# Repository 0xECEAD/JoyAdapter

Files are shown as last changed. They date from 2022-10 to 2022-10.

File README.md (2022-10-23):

# JoyAdapter

Another 8-bit Atari Joystick to USB adapter.

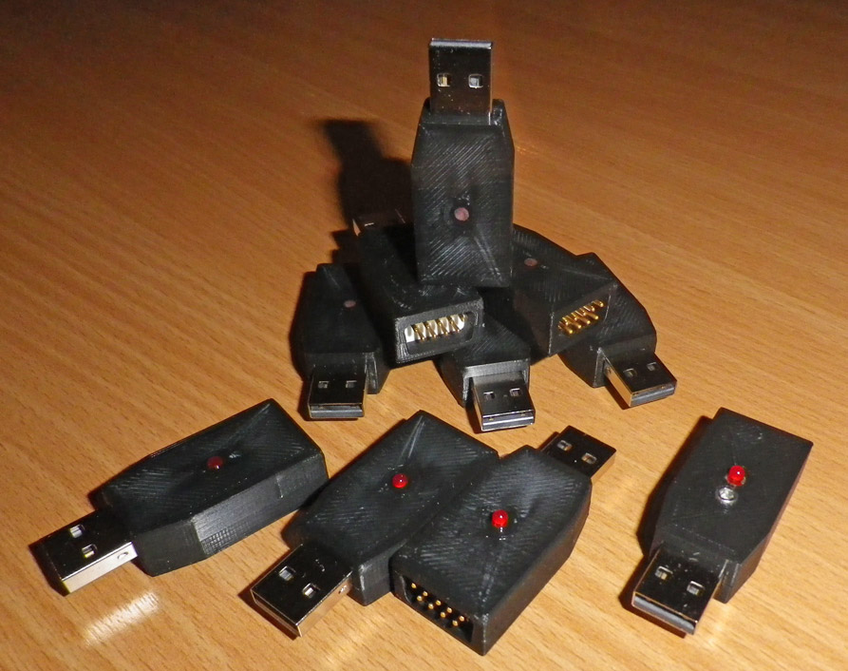
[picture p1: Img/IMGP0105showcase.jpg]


There are dozens of similar converters available, but I wanted one in a sleek form factor.
It is about the size of the iconic Atari connector itself. 

It is a standard USB-HID class (Joystick) device, generally no drivers required. It has 2 buttons and 2-axis (non configurable). No POT/Paddle inputs only digital (switch to ground) inputs. 

The LED flashes on connect and movement/button action.

## PCB:

schematic: [pdf](Board/schema.pdf)
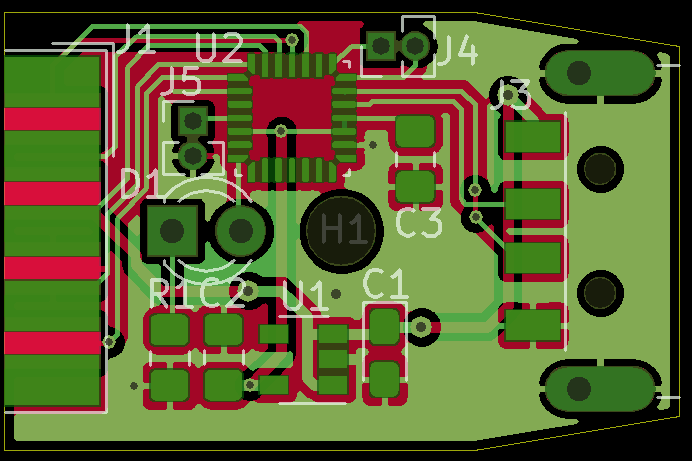
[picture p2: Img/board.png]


### Pinout J1 Atari:
Connector  [Wikipedia](https://en.wikipedia.org/wiki/Atari_joystick_port)

| Pin | Function | Pin | Function |
| --- | --- | --- | --- |
| 1 | Up | 6 | Button 1 |
| 2 | Down | 7 | +5V |
| 3 | Left | 8 | Ground |
| 4 | Right | 9 | Button 2 |
| 5 | N.C. |

**Note:** +5V on pin 7 (not fused or limitied or protected) can damage you USB host if shorted.
5V is not required for most (passive) joysticks i know, so you could pull pin 7 the out of the connector to be safe.

### Parts: 

|Qty|Ref(s)|Value|Manufacturer|Note|Datasheet|
| --- | --- | --- | --- | --- | --- |
|1|C1|4u7F||Tantalum||
|1|C2|1uF||||
|1|C3|100nF||||
|1|D1|L-424IDT|Kingbright|FlatTop|[pdf](https://nl.mouser.com/datasheet/2/216/L-424IDT(Ver.12A)-795377.pdf)|
|1|H1|MountingHole||2.5mm||
|1|J1|DB9 Male||Solder Straight, shell removed||
|1|J3|USB PLUG Type A|Keystone Electronics|SMD|[pdf](https://www.mouser.com/datasheet/2/215/31-744008.pdf)|
|2|J4, J5|Connector 1x2||pitch 1.27mm||
|1|R1|68Ω||||
|1|U1|XC6220B331MR|Torex Semiconductor||[pdf](https://www.torexsemi.com/file/xc6220/XC6220.pdf)|
|1|U2|STM32F042G6Ux|STMicroelectronics|QFN28 4x4mm|[pdf](http://www.st.com/st-web-ui/static/active/en/resource/technical/document/datasheet/DM00105814.pdf)|

Notes: 
- The J1 shell is actually a **DE**-type (common mistake, even KiCad fails this)
- Any low-drop voltage regulator for U1 (SOT23-5 package) either 3V or 3V3, e.q. XC6220B331MR or AP7383-30W5.
- U2 is a STM32F042G6Ux controller, it features crystal-less USB, and 5V tolerant inputs.
- The SWD programming connector was split into two, J4 and J5 due to size restrictions.

### Construction:

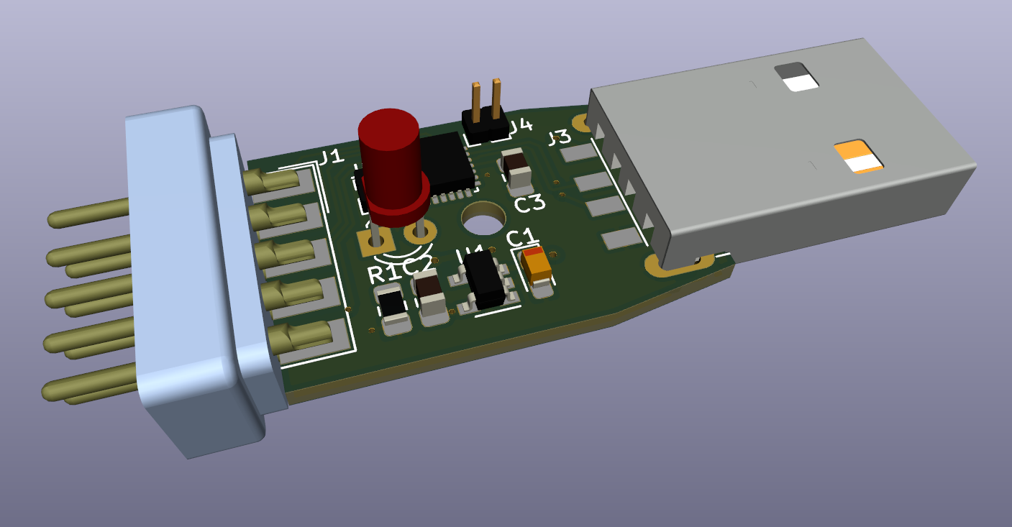
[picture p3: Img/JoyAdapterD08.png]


Manufacture the PCB with FR4 thickness 1.2mm. (Normal 1.6mm will not fit between the pins of J1).

J1 is a standard DSUB 9pin Male connector. Remove the shell with cutters and pliers and some force.
The remaining inner part can be mounted with the PCB between the pins. 

Solder the LED so the flat top aligns nicely with the top side of the case.

## Case:

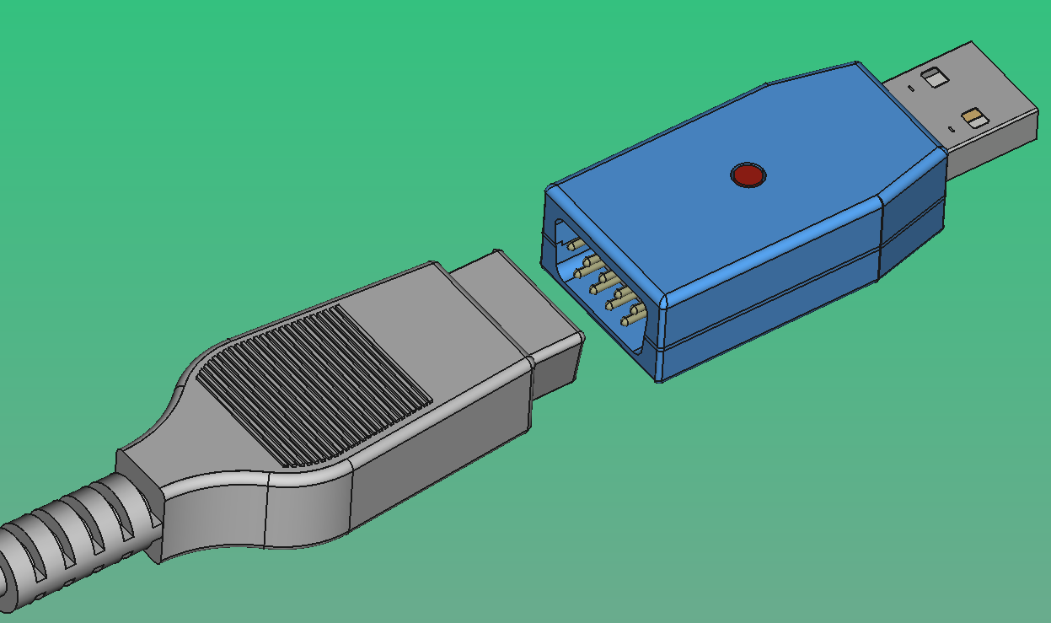
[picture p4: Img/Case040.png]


Print the Bottom and Top part of the case on your 3D printer (i used a Ultimaker S5).
Use a M2.5 x 8mm Hex Socket Head Cap Screw to join bottom case and top case together.

## Software:

Project setup was done with [STM CubeMX](https://www.st.com/en/development-tools/stm32cubemx.html), further implementation with [VisualGDB](https://visualgdb.com/).
The [Descriptor Tool](https://www.usb.org/document-library/hid-descriptor-tool) was used to design the HID Report.
Its a fairly simple source code, you can adjust it to you favorite development environment.

### Latency:

Updates 100x per second, reason mostly to reduce contact bounce. 
In theory you could send at 1kHz for LowSpeed USB or 8kHz for FullSpeed USB, but you may want to include some debounce logic.
Current implementation thus updates every change in a 10ms interval, faster then most screen refresh rates of retro games. 

## Compatibility
Windows 98/XP/Vista/7/8/10/11, Mac OSX, Linux, RaspberryPI, MiSTer. 

### Tested Devices
The Arcade by S.T.C. Rotterdam

### Design Software

KiCad v6.0.7 + GerberView v2.6.1
FreeCAD v0.19
Ultimaker Cura v4.6.2

Descriptor Tool, Version 2.4
VisualGDB v5.6r8 + STM CubeMX v6.5

### Demo
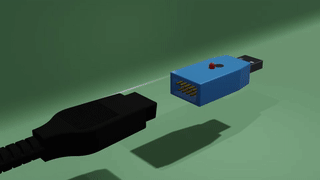
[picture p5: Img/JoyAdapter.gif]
movie


## Credits
(c) 2019 Enceladus

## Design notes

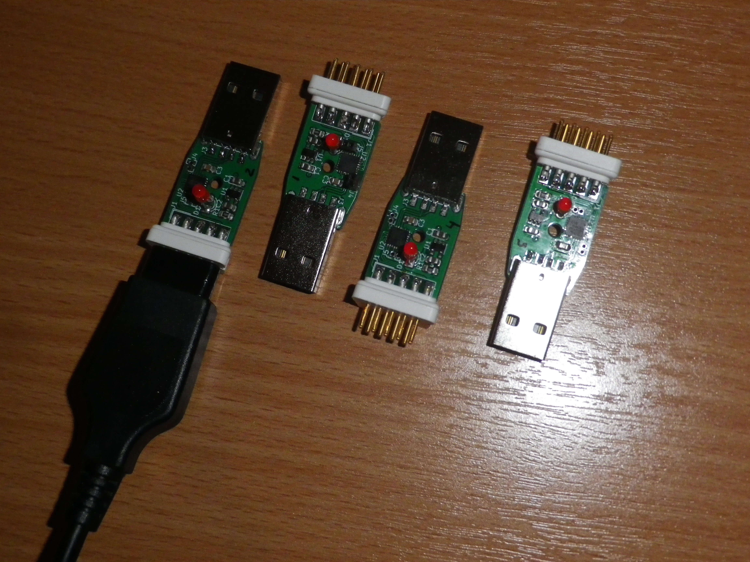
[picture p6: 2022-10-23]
Img/IMGP0094.JPG

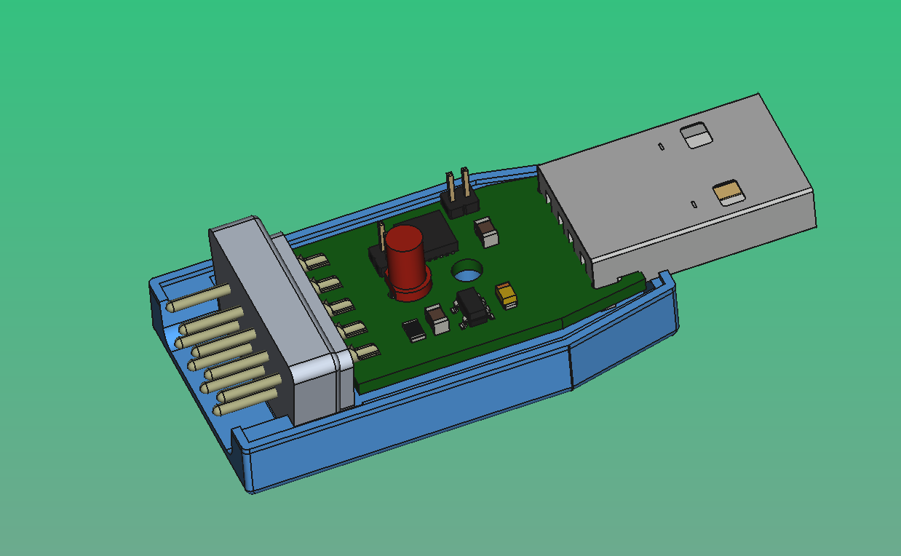
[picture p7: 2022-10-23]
Img/Case041.png

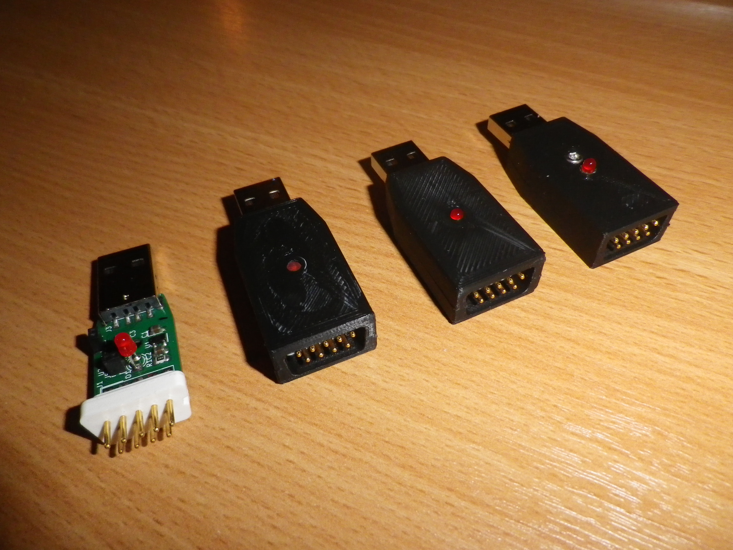
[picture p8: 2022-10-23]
Img/IMGP0100.JPG

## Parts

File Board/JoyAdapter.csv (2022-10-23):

Source: | D:\tmp\JoyAdapter.kicad_sch
Date: | 19/10/2022 13:25:23
Tool: | Eeschema (6.0.7)
Generator: | D:\Tools\KiCad\bin\scripting\plugins/bom_csv_grouped_by_value.py
Component Count: | 12
Individual Components:
Item | Qty | Reference(s) | Value | LibPart | Footprint | Datasheet
 |  | C1 | 4u7F | Device:C_Polarized |  | ~
 |  | C2 | 1uF | Device:C | Capacitor_SMD:C_0805_2012Metric_Pad1.15x1.40mm_HandSolder | ~
 |  | C3 | 100nF | Device:C | Capacitor_SMD:C_0805_2012Metric_Pad1.15x1.40mm_HandSolder | ~
 |  | D1 | L-424IDT | Device:LED | LED_THT:LED_D3.0mm_FlatTop | ~
 |  | H1 | MountingHole | Mechanical:MountingHole | MountingHole:MountingHole_2.5mm | ~
 |  | J1 | DB9_Male | Connector:DB9_Male | Parts:DSUB-9_Male_EdgeMount_P2.77mm | ~
 |  | J3 | USB_B | Connector:USB_B | Parts:USB_A_Lumberg_2410-08 | ~
 |  | J4 | Conn_01x02 | Connector_Generic:Conn_01x02 | Connector_PinHeader_1.27mm:PinHeader_1x02_P1.27mm_Vertical | ~
 |  | J5 | Conn_01x02 | Connector_Generic:Conn_01x02 | Connector_PinHeader_1.27mm:PinHeader_1x02_P1.27mm_Vertical | ~
 |  | R1 | 68 | Device:R | Resistor_SMD:R_0805_2012Metric_Pad1.15x1.40mm_HandSolder | ~
 |  | U1 | XC6220B331MR | Regulator_Linear:XC6220B331MR | Package_TO_SOT_SMD:SOT-23-5 | https://www.torexsemi.com/file/xc6220/XC6220.pdf
 |  | U2 | STM32F042G6Ux | MCU_ST_STM32F0:STM32F042G6Ux | Package_DFN_QFN:QFN-28_4x4mm_P0.5mm | http://www.st.com/st-web-ui/static/active/en/resource/technical/document/datasheet/DM00105814.pdf
Collated Components:
Item | Qty | Reference(s) | Value | LibPart | Footprint | Datasheet
1 | 1 | C1 | 4u7F | Device:C_Polarized |  | ~
2 | 1 | C2 | 1uF | Device:C | Capacitor_SMD:C_0805_2012Metric_Pad1.15x1.40mm_HandSolder | ~
3 | 1 | C3 | 100nF | Device:C | Capacitor_SMD:C_0805_2012Metric_Pad1.15x1.40mm_HandSolder | ~
4 | 1 | D1 | L-424IDT | Device:LED | LED_THT:LED_D3.0mm_FlatTop | ~
5 | 1 | H1 | MountingHole | Mechanical:MountingHole | MountingHole:MountingHole_2.5mm | ~
6 | 1 | J1 | DB9_Male | Connector:DB9_Male | Parts:DSUB-9_Male_EdgeMount_P2.77mm | ~
7 | 1 | J3 | USB_B | Connector:USB_B | Parts:USB_A_Lumberg_2410-08 | ~
8 | 2 | J4, J5 | Conn_01x02 | Connector_Generic:Conn_01x02 | Connector_PinHeader_1.27mm:PinHeader_1x02_P1.27mm_Vertical | ~
9 | 1 | R1 | 68 | Device:R | Resistor_SMD:R_0805_2012Metric_Pad1.15x1.40mm_HandSolder | ~
10 | 1 | U1 | XC6220B331MR | Regulator_Linear:XC6220B331MR | Package_TO_SOT_SMD:SOT-23-5 | https://www.torexsemi.com/file/xc6220/XC6220.pdf
11 | 1 | U2 | STM32F042G6Ux | MCU_ST_STM32F0:STM32F042G6Ux | Package_DFN_QFN:QFN-28_4x4mm_P0.5mm | http://www.st.com/st-web-ui/static/active/en/resource/technical/document/datasheet/DM00105814.pdf

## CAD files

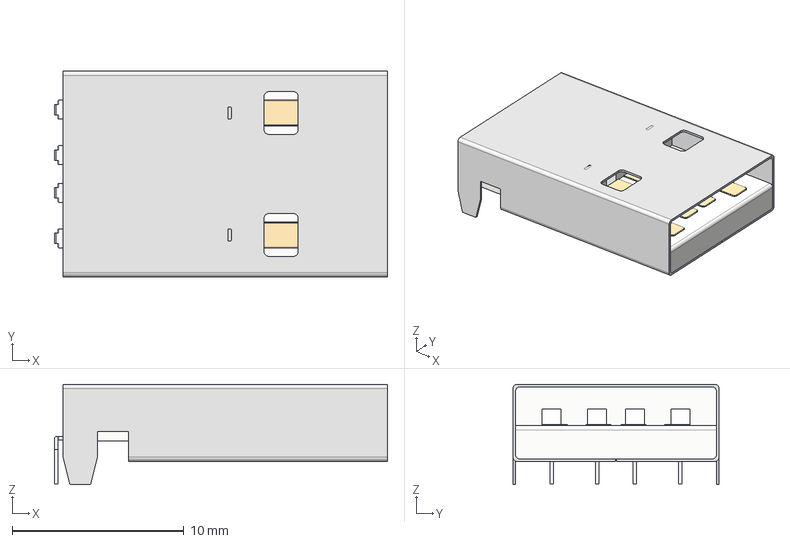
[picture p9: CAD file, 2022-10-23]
Board/USB A PCB Connector.step
19.4 x 12.0 x 5.85 mm

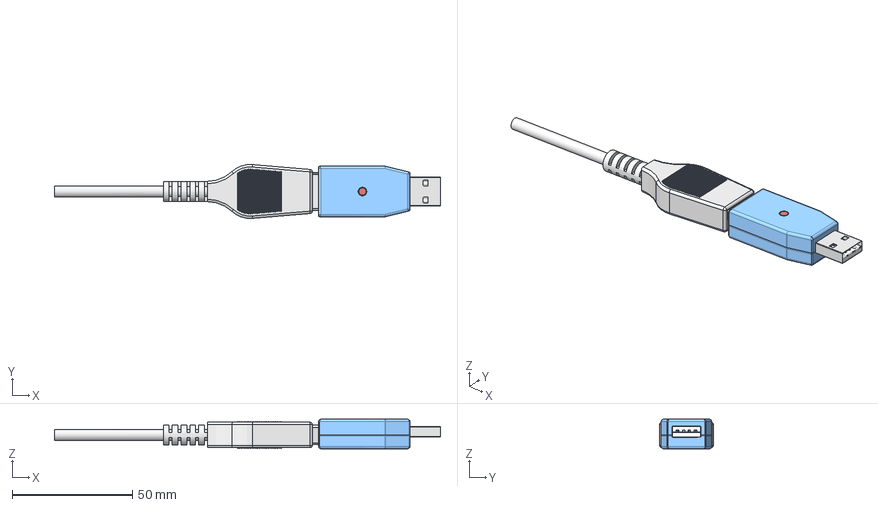
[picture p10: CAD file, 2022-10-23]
Case/JoyAdapter.FCStd
160.3 x 22.4 x 12.3 mm
M2.5x8
FinalTop
FinalBottom

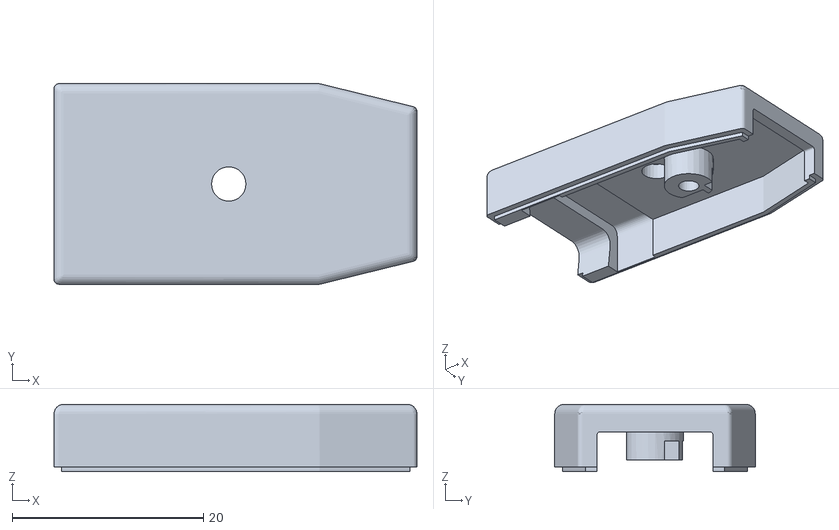
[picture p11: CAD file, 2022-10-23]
Release/Stl/CaseTop.stl
38.0 x 21.0 x 7.05

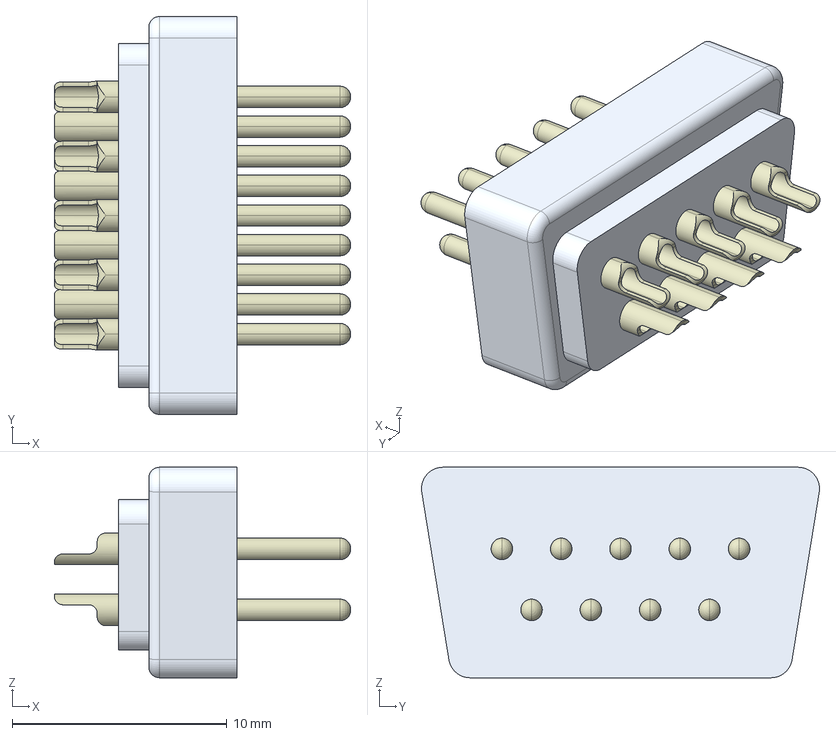
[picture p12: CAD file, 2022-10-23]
Board/DE9-P.step
13.8 x 18.5 x 9.80 mm
Solder3
Pin3
Solder1
Solder2
Solder4
Solder5
Pin1
Pin2
Pin4
Pin5
Solder7
Pin7
Solder8
Pin8
Solder6
Pin6
Solder9
Pin9

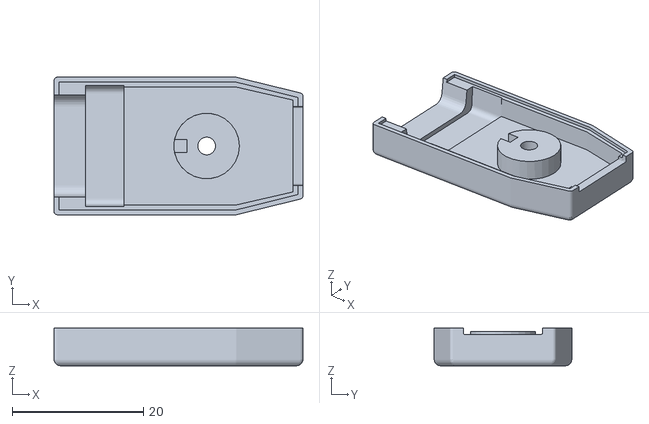
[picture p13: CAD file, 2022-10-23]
Release/Stl/CaseBottom.stl
38.0 x 21.0 x 5.75

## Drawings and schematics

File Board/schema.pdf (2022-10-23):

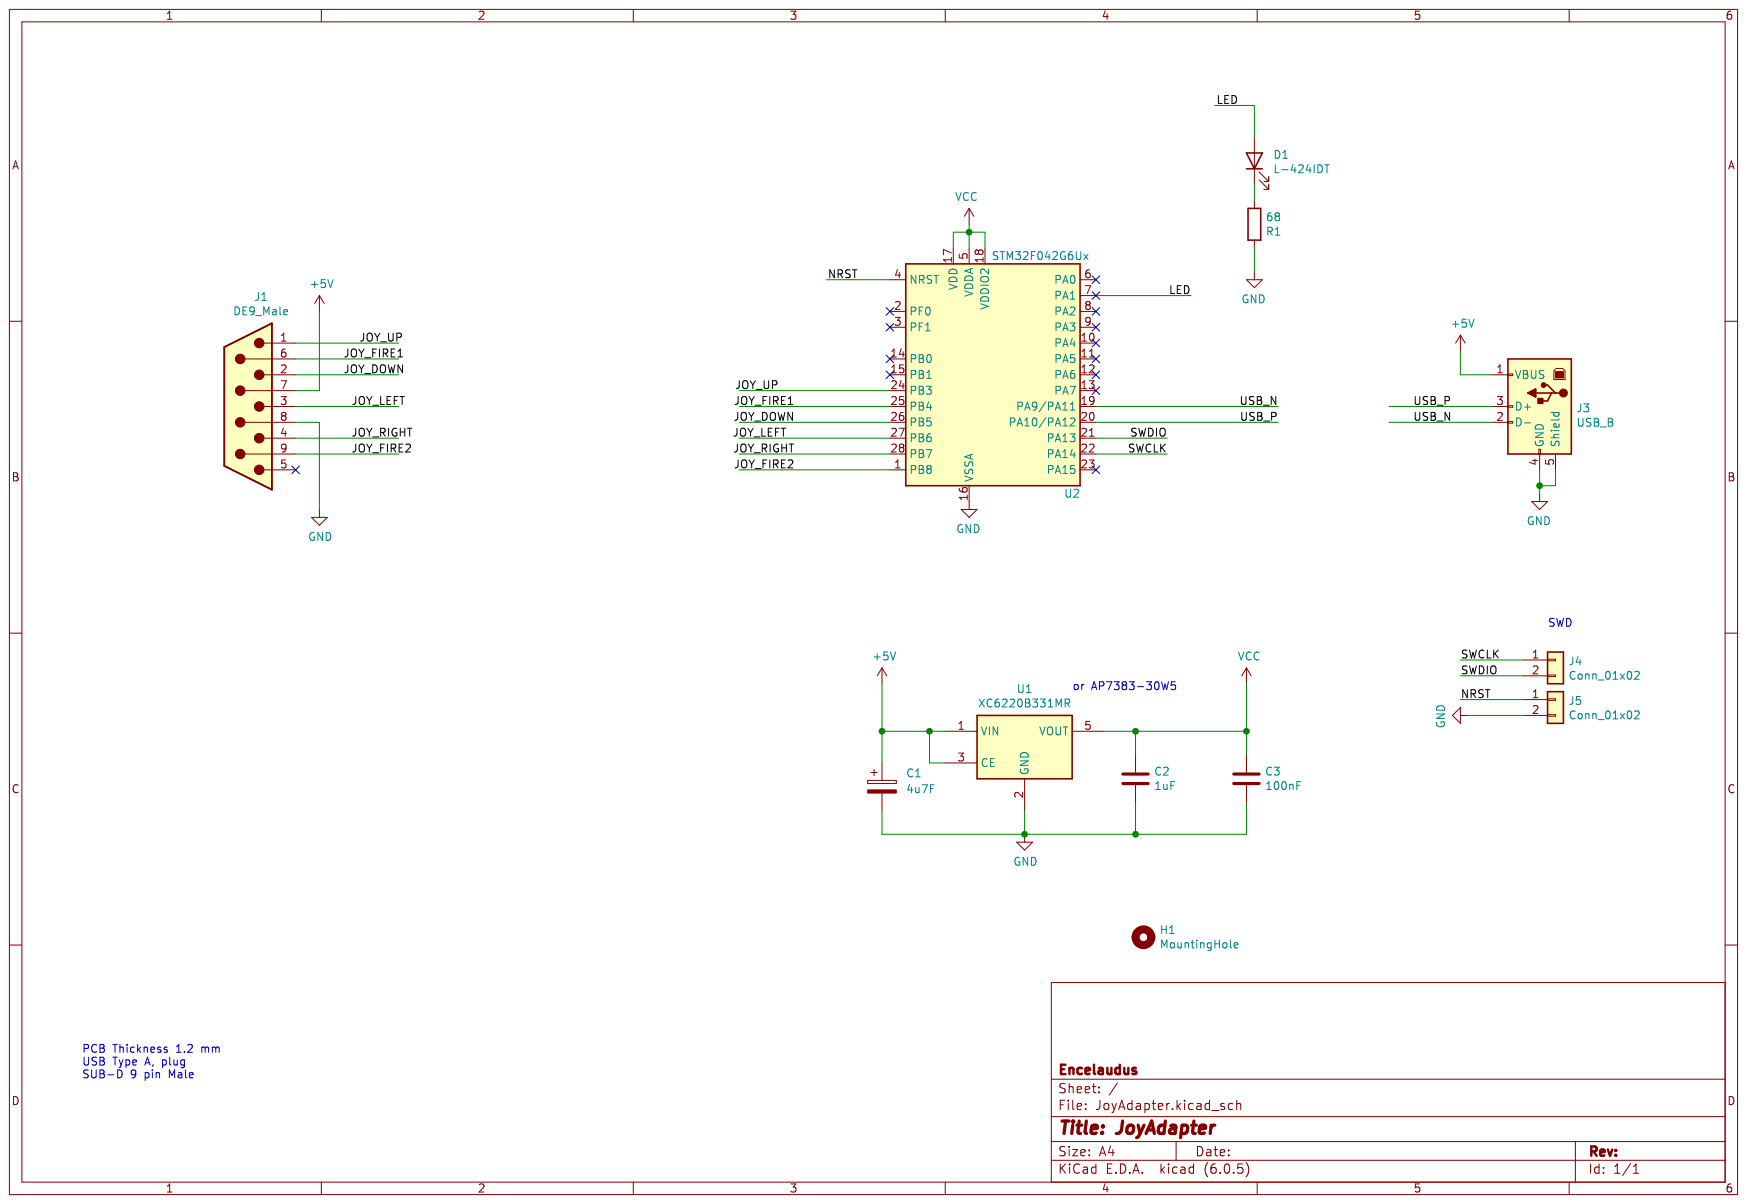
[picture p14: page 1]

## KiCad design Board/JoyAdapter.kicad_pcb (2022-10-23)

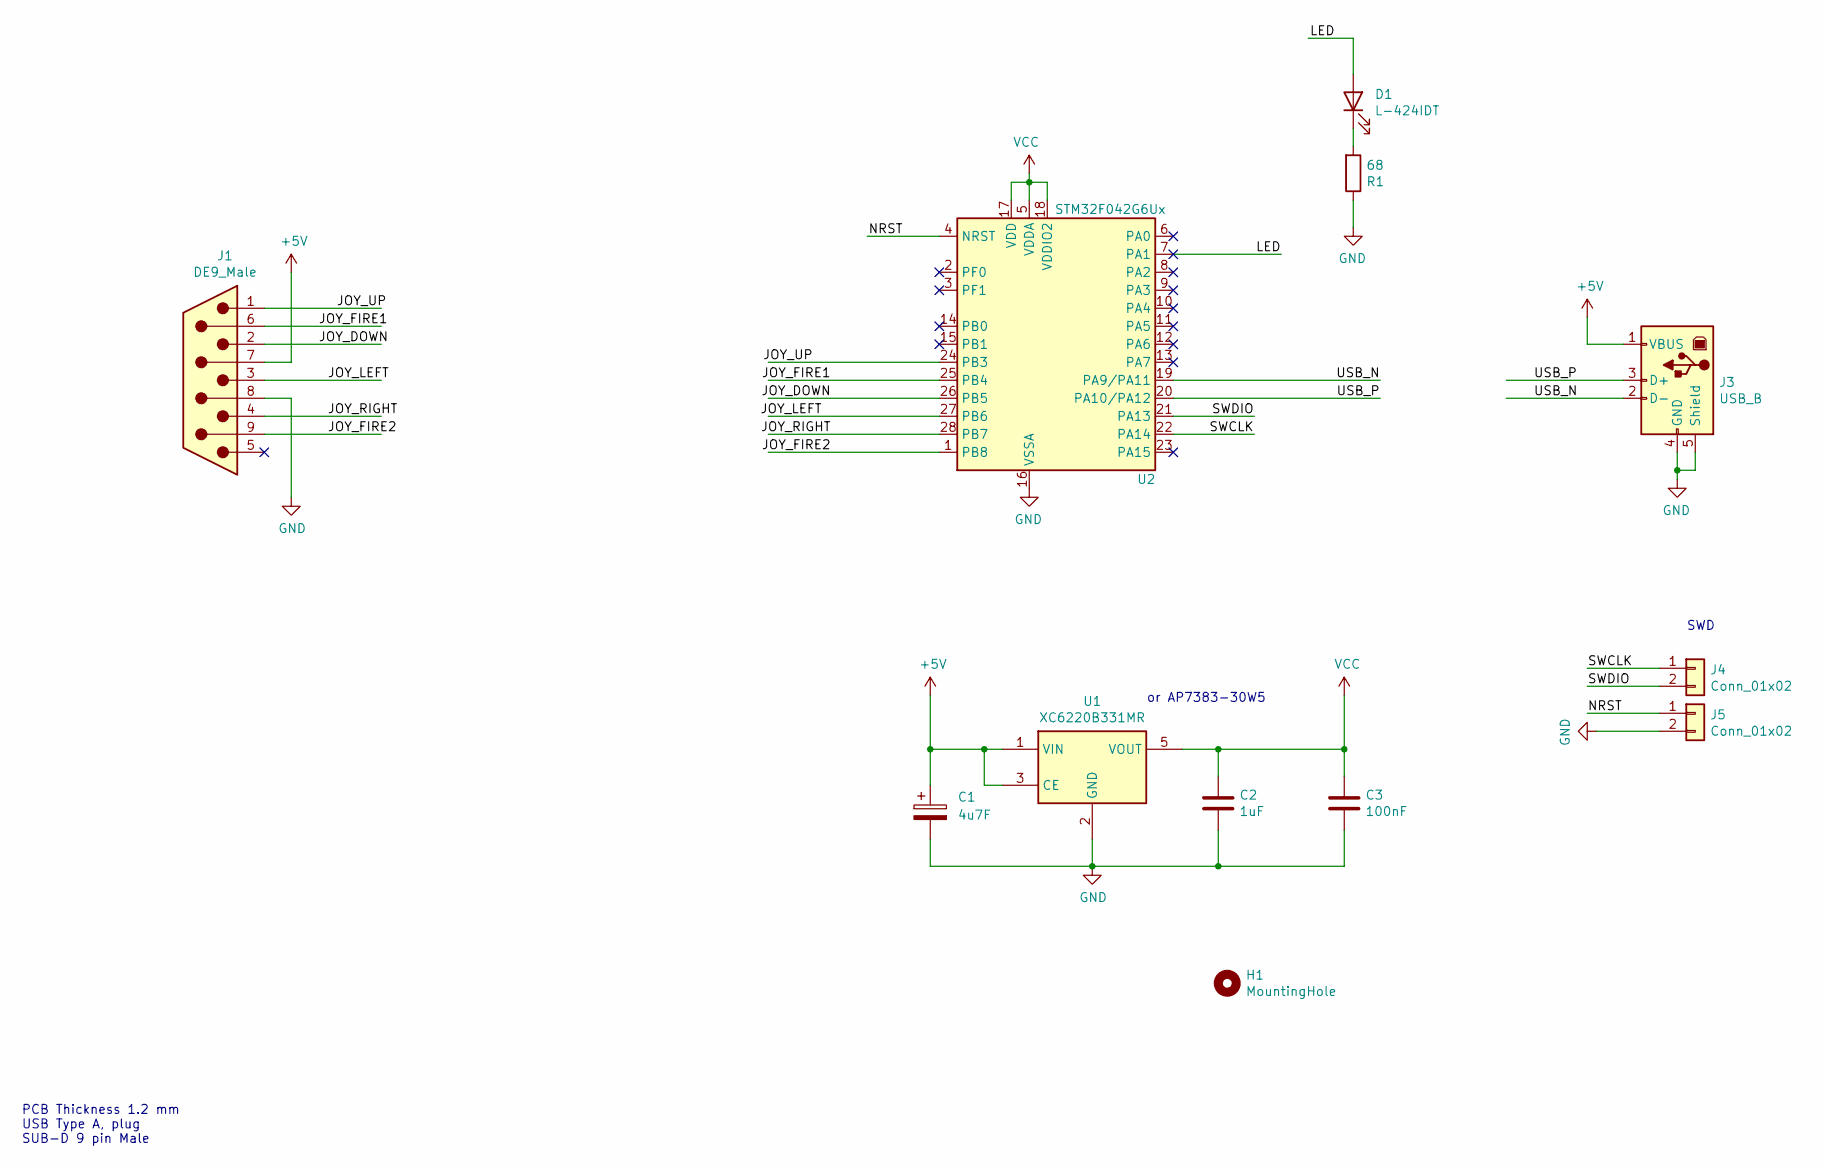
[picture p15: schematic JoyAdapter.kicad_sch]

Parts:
C1: 4u7F
C2: 1uF; C_0805_2012Metric_Pad1.15x1.40mm_HandSolder
C3: 100nF; C_0805_2012Metric_Pad1.15x1.40mm_HandSolder
D1: L-424IDT; LED_D3.0mm_FlatTop
H1: MountingHole; MountingHole_2.5mm
J1: DE9_Male; DSUB-9_Male_EdgeMount_P2.77mm
J3: USB_B; USB_A_Lumberg_2410-08
J4, J5: Conn_01x02; PinHeader_1x02_P1.27mm_Vertical
R1: 68; R_0805_2012Metric_Pad1.15x1.40mm_HandSolder
U1: XC6220B331MR; SOT-23-5
U2: STM32F042G6Ux; QFN-28_4x4mm_P0.5mm

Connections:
+5V: C1.1, J1.7, J3.1 (VBUS), U1.1 (VIN), U1.3 (CE)
/JOY_DOWN: J1.2, U2.26 (PB5)
/JOY_FIRE1: J1.6, U2.25 (PB4)
/JOY_FIRE2: J1.9, U2.1 (PB8)
/JOY_LEFT: J1.3, U2.27 (PB6)
/JOY_RIGHT: J1.4, U2.28 (PB7)
/JOY_UP: J1.1, U2.24 (PB3)
/LED: D1.2 (A), U2.7 (PA1)
/NRST: J5.1, U2.4 (NRST)
/SWCLK: J4.1, U2.22 (PA14)
/SWDIO: J4.2, U2.21 (PA13)
/USB_N: J3.2 (D-), U2.19 (PA9/PA11)
/USB_P: J3.3 (D+), U2.20 (PA10/PA12)
GND: C1.2, C2.2, C3.2, J1.8, J3.4 (GND), J3.5 (Shield), J5.2, R1.1, U1.2 (GND), U2.16 (VSSA)
unnamed: D1.1 (K), R1.2
VCC: C2.1, C3.1, U1.5 (VOUT), U2.5 (VDDA), U2.17 (VDD), U2.18 (VDDIO2)

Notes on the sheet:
or AP7383-30W5
SWD
PCB Thickness 1.2 mm USB Type A, plug SUB-D 9 pin Male

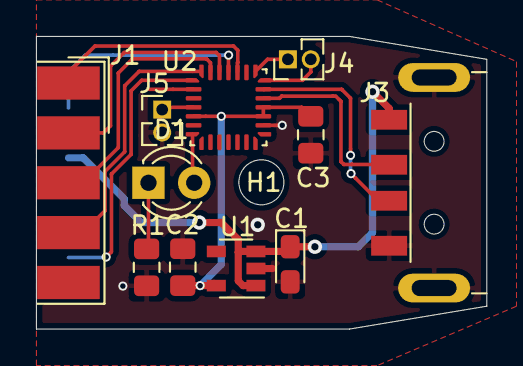
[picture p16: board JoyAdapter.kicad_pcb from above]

Board: 2 copper layers, 25.0 x 16.3 mm, 12 parts (0 on the bottom side), 16 nets.

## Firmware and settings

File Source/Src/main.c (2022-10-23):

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

/* Includes ------------------------------------------------------------------*/
#include "main.h"
#include "usb_device.h"

/* USER CODE BEGIN Includes */
#include "usbd_custom_hid_if.h"
/* USER CODE END Includes */

TIM_HandleTypeDef htim2;
TIM_HandleTypeDef htim14;

/* USER CODE BEGIN PV */
volatile int flag = 0;

/* USER CODE END PV */

void SystemClock_Config(void);
static void MX_GPIO_Init(void);
static void MX_TIM2_Init(void);
static void MX_TIM14_Init(void);
/* USER CODE BEGIN 0 */
void HAL_TIM_PeriodElapsedCallback(TIM_HandleTypeDef* htim)
{
   flag = 1;
}
/* USER CODE END 0 */

/**
  * @brief  The application entry point.
  * @retval int
  */
int main(void)
{
  

  /* MCU Configuration--------------------------------------------------------*/

  /* Reset of all peripherals, Initializes the Flash interface and the Systick. */
  HAL_Init();

  /* Configure the system clock */
  SystemClock_Config();

  /* Initialize all configured peripherals */
  MX_GPIO_Init();
  MX_TIM2_Init();
  MX_TIM14_Init();
  MX_USB_DEVICE_Init();
  /* USER CODE BEGIN 2 */

   int buttons = GPIOB->IDR & (JOY_LEFT_Pin | JOY_RIGHT_Pin | JOY_UP_Pin | JOY_DOWN_Pin | JOY_FIRE1_Pin | JOY_FIRE2_Pin);

   uint8_t report_data[USBD_CUSTOMHID_OUTREPORT_BUF_SIZE];
   //int delay = 75;
   HAL_TIM_PWM_Start(&htim2, TIM_CHANNEL_2);
   HAL_TIM_Base_Start_IT(&htim14);
   int pwm = 999;
  /* USER CODE END 2 */

  /* Infinite loop */
  /* USER CODE BEGIN WHILE */
   while (1)
   {
      if (flag == 0) continue;
      flag = 0;      // 100x per sec

      if (pwm > 80) pwm -= 80; else pwm = 0;
      TIM2->CCR2 = pwm;

      int bs2 = GPIOB->IDR & (JOY_LEFT_Pin | JOY_RIGHT_Pin | JOY_UP_Pin | JOY_DOWN_Pin | JOY_FIRE1_Pin | JOY_FIRE2_Pin);
      if (bs2 != buttons)
      {
         buttons = bs2;
         report_data[0] = ((buttons & JOY_FIRE1_Pin) == 0 ? 1 : 0) | ((buttons & JOY_FIRE2_Pin) == 0 ? 2 : 0);
         report_data[1] = (buttons & JOY_LEFT_Pin) == 0 ? -127 : (buttons & JOY_RIGHT_Pin) == 0 ? 127 : 0;
         report_data[2] = (buttons & JOY_UP_Pin) == 0 ? -127 : (buttons & JOY_DOWN_Pin) == 0 ? 127 : 0;
         HID_SendReport(report_data);

         if (pwm < 750) pwm += 250; else pwm = 1000;
         TIM2->CCR2 = pwm;
      }
    /* USER CODE END WHILE */

    /* USER CODE BEGIN 3 */
   }
  /* USER CODE END 3 */
}

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


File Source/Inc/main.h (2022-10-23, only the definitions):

#define JOY_FIRE2_Pin GPIO_PIN_8
#define JOY_FIRE2_GPIO_Port GPIOB
#define JOY_UP_Pin GPIO_PIN_3
#define JOY_UP_GPIO_Port GPIOB
#define JOY_FIRE1_Pin GPIO_PIN_4
#define JOY_FIRE1_GPIO_Port GPIOB
#define JOY_DOWN_Pin GPIO_PIN_5
#define JOY_DOWN_GPIO_Port GPIOB
#define JOY_LEFT_Pin GPIO_PIN_6
#define JOY_LEFT_GPIO_Port GPIOB
#define JOY_RIGHT_Pin GPIO_PIN_7
#define JOY_RIGHT_GPIO_Port GPIOB

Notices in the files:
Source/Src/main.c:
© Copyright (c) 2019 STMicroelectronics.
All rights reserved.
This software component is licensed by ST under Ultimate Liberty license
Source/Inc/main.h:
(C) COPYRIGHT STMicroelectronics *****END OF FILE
